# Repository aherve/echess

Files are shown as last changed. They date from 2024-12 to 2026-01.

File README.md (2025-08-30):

# eChess: play online chess, but over the board

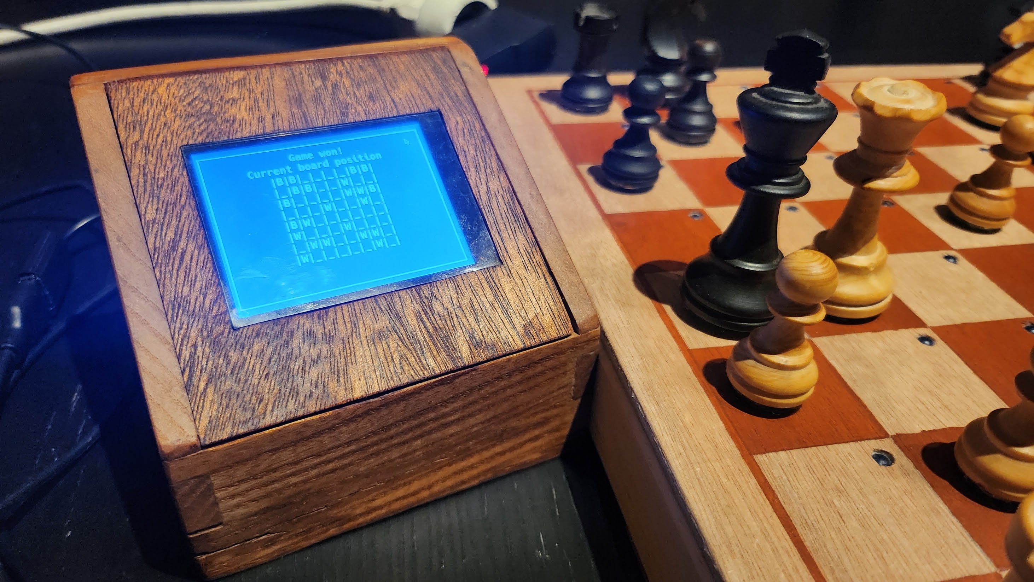
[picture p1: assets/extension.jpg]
extension


https://github.com/user-attachments/assets/bde2e431-92bb-4959-bb7b-e80072c71205

_Demo game against a lichess bot. The phone showcases the game for demo purposes, but isn't actually required to play_

## How it works

- The board is equipped with 64 hall effect sensors, and 64 LEDs.
- The board can communicate via usb to a nodejs program that runs on an embedded raspberry PI with touchscreen
- The program can communicate with both lichess API and the physical board

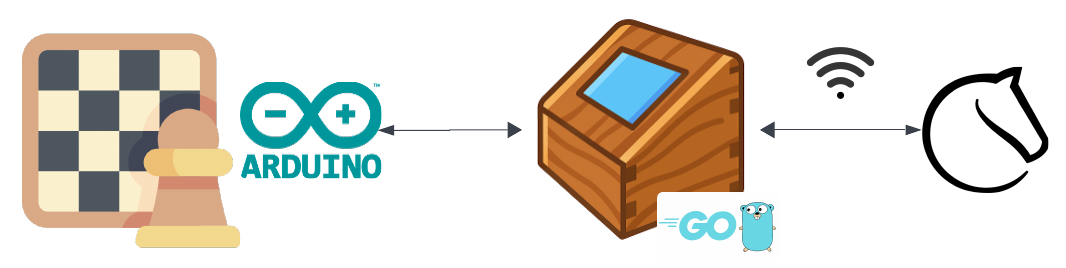
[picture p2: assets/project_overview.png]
overview


### Piece detection

The general principle is to hide magnetic hall effect sensors under the board to detect piece presence. White & black pieces have a hidden magnet in them, in different orientations, respectively

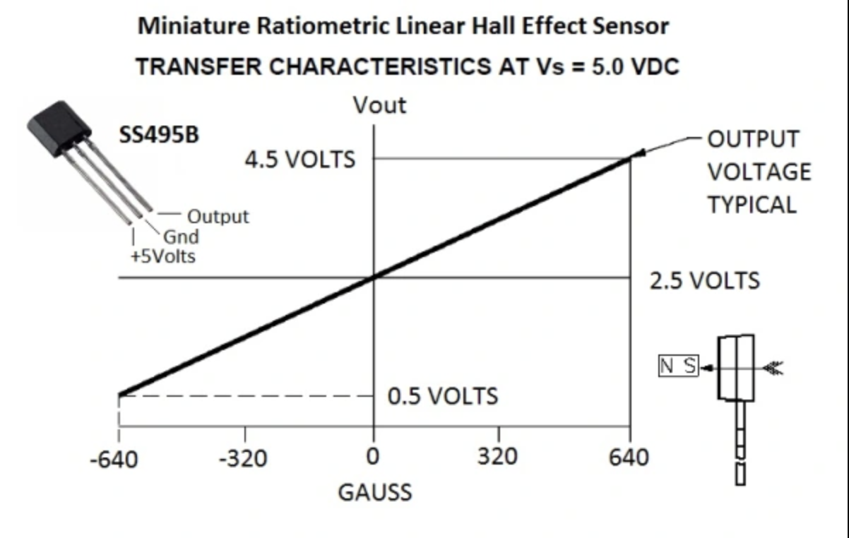
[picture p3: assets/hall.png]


Using linear sensors we are then able to detect between 3 distinct states:

- white piece (low voltage)
- black piece (high voltage)
- no piece (~ half the supply voltage)

In addition to the sensors, a 8x8 LED matrix is used to display the opponent's moves on the board. An arduino microcontroller interfaces with an embedded go program to control the LEDs, read the sensors, and communicate with the lichess API.

## Showing the moves

Each square is equipped with a blue LED that can be lit to signal the opponent's move. It's bright enough that we don't miss a move, and discreet enough that it doesn't distract from the game.

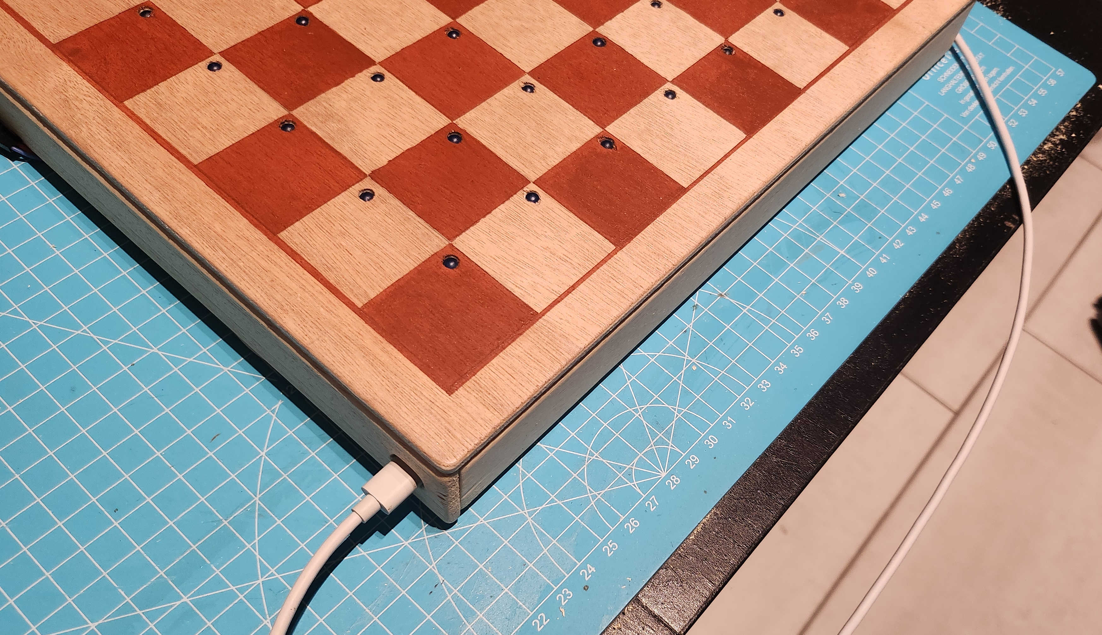
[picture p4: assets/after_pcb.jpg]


## The electronics

For the board to work, is is necessary to:

- read inputs from the program, and light any combination of leds on a 8x8 grid
- read the state of 64 hall effect sensors in near real time, and send the state to the program whenever a change is detected

Since the arduino has a limited number of pins, two 74HC595 shift registers are used to control the LEDs with multiplexing, and an additional 74HC4051 multiplexer is used to control the sensor rows. Each of the sensor outputs are connected to one of the analog inputs of the microcontroller (arduino conveniently has 8 of them).

### The sensor matrix

According to their spreadsheet, the power-on time of the the hall sensors is somewhere from 175μs to 300μs. This is slow enough that we can't use multiplexing to power the sensors. Instead I went for a 8x8 matrix where all of the sensors are always powered. Their input readings are then selected using some BJT transistors whose switch time is in the order of 30ns (so about 8 500 times faster than the sensors power-on time)

<figure>
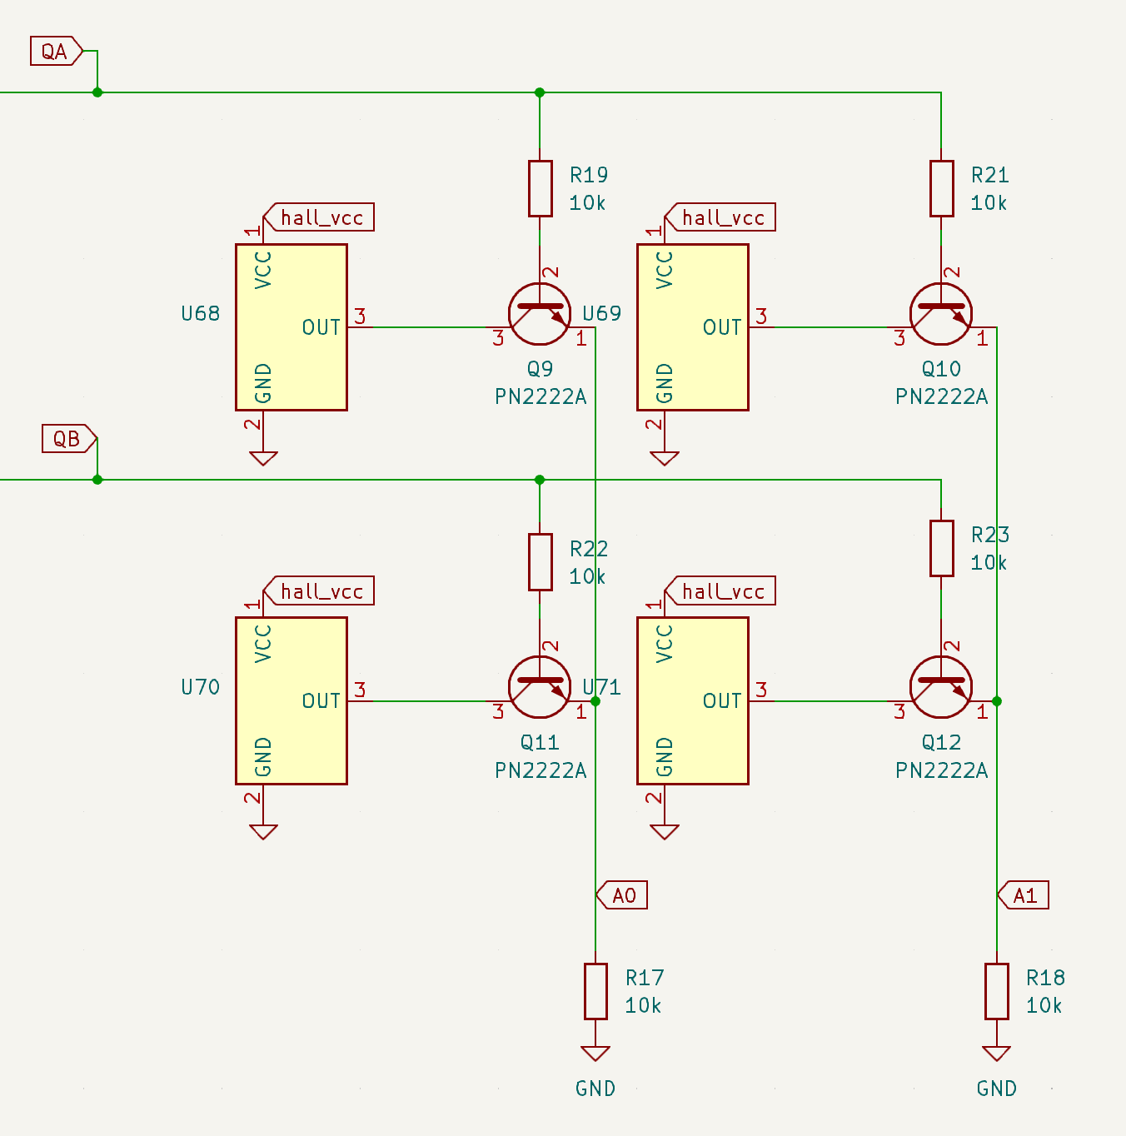
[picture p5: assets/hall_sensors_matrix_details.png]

<figcaption>Details of the sensor matrix, only 4 sensors are shown. Sending <i>QA=1</i>, <i>QB=0</i> and reading <i>A1</i> input would provide a reading of the bottom-right sensor of this diagram</figcaption>
</figure>

### Electronics overview

The three 74HC595 shift registers are chained, and connected to the arduino as follows(only 4 sensors are shown for simplicity):

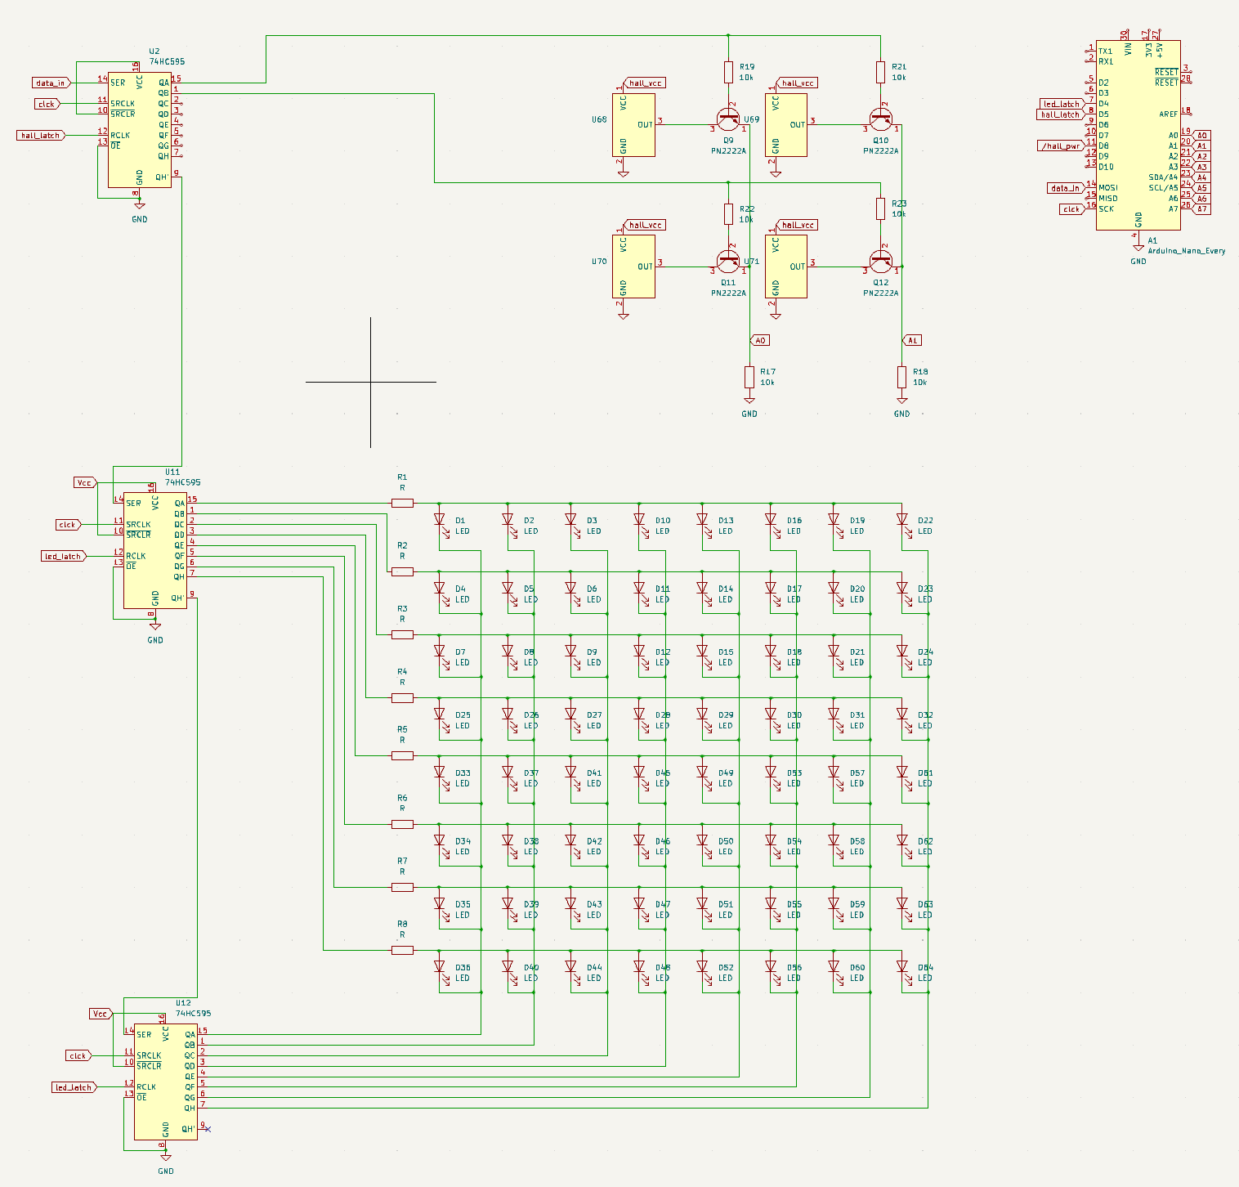
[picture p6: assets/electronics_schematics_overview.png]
overview

_complete overview of the electronics. Full kiCad files can be found in the [kiCad](kiCad) directory_

With this setup, [the microcontroller](arduino/arduino.ino) can use multiplexing to control the LEDs and read the sensors in near real time, while using very few pins from the microcontroller.

### The final build

For the build I soldered 64 leds, hall effect sensors, and transistors directly to a wooden board I build and painted. The shift-register ICs are wired to the microcontroller thanks to a custom PCB [ whose files can be found here ](eBoard_pcb)

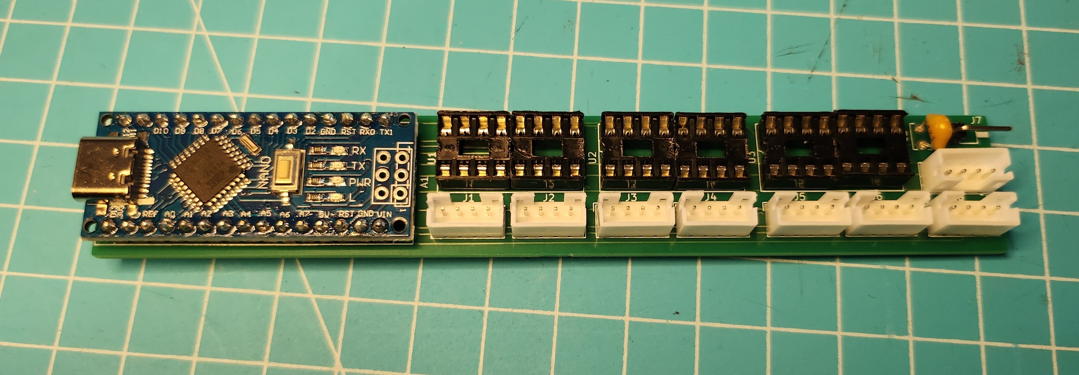
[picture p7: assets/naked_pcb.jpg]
pcb

_soldered pcb with arduino nano, IC sockets and some connectors_

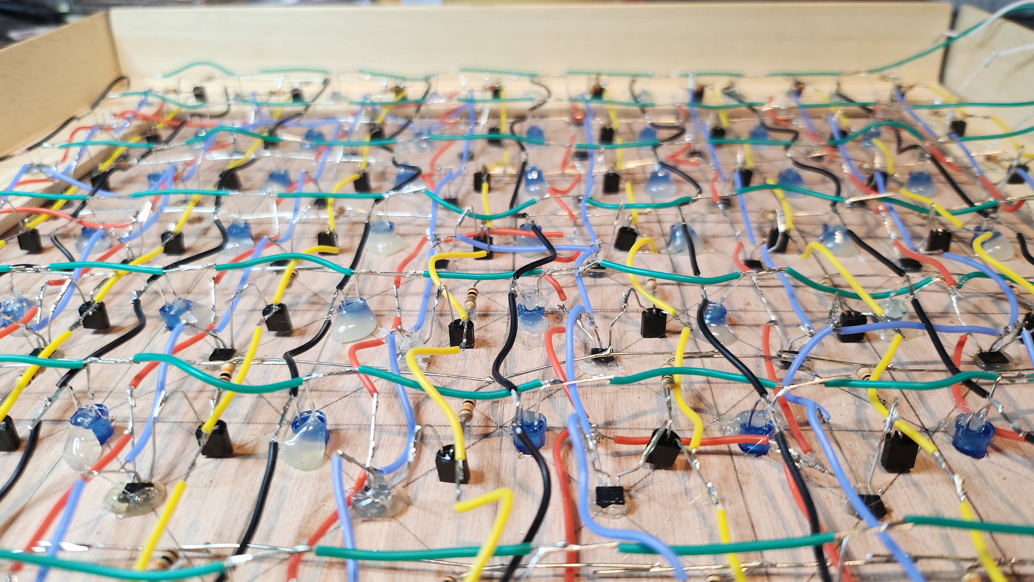
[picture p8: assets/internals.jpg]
internal

_internal view of the board_

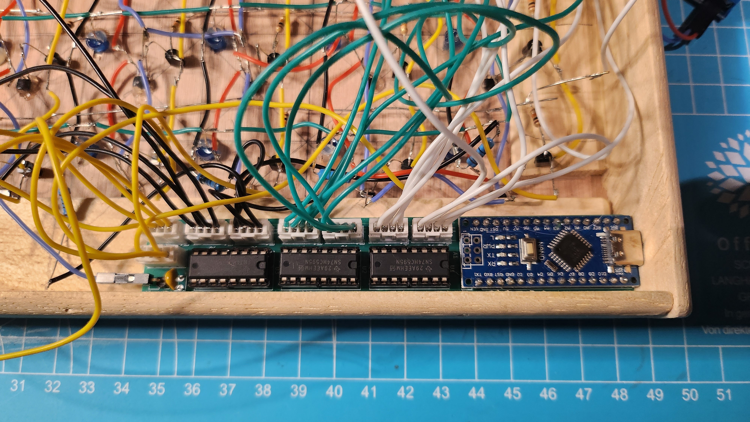
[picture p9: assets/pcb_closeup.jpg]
pcb closeup

_closeup of the pcb after installation_

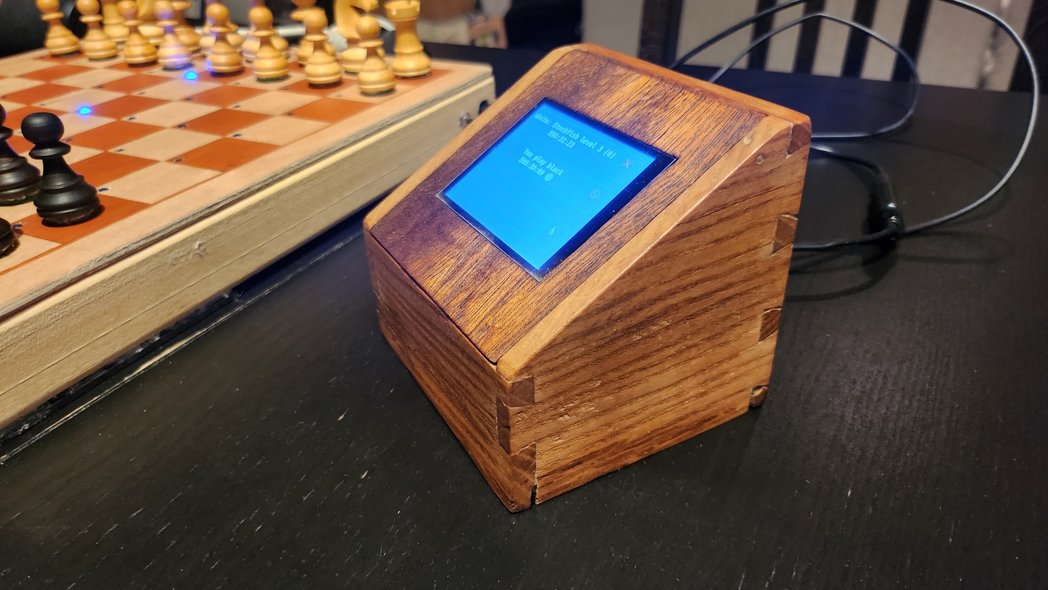
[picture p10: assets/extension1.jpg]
extension1


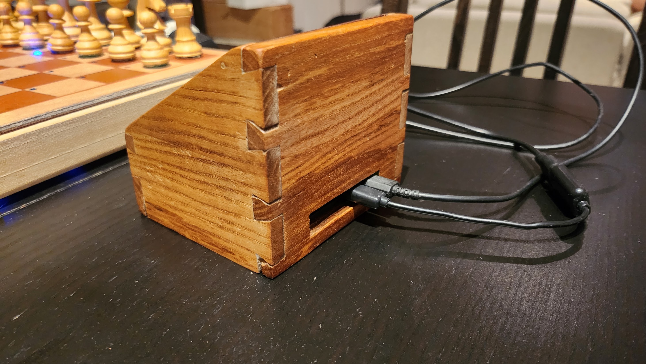
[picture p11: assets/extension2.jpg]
extension2


## Microconctroller setup

Arduino nano is used. It's cheap, small, and conveniently has 8 analog inputs, which is perfect for this use case.

## workflow

The arduino loop does the following:

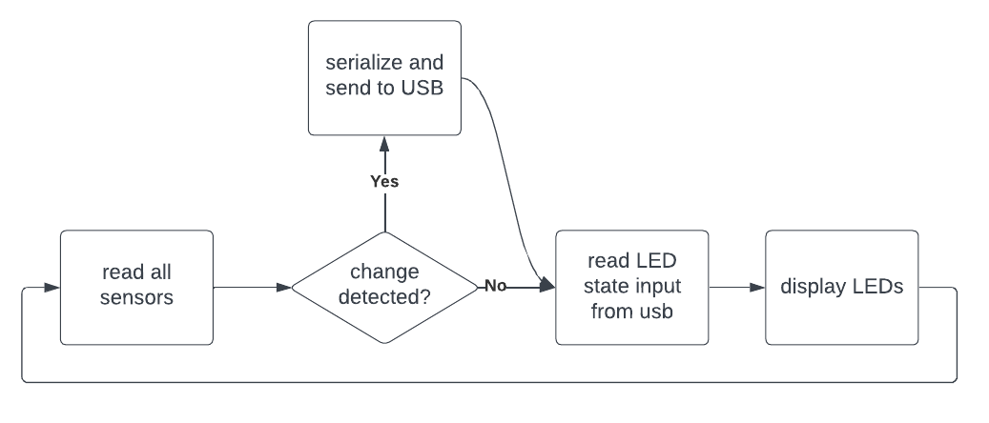
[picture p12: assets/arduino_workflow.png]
workflow


1. **Read all the sensors**

   Using multiplexing, read all states from the 64 hall sensors and build a board state from it. If a state change is detected, then we serialize the board state and send it to the computer.

2. **Read the LED input state**

   Read from usb and set the desired LED state

3. **Display the LEDs**

   For each lit LED from the input state, light the corresponding LED on the board, wait 2ms, and turn it off.

Since we are multiplexing the display, the entire loop needs to be _fast_. Fast enough that you don't see any flickering while we are reading 64 sensors and communicating via USB between each LED blink.

## Serializing the position

A chess board has a very convenient size of 8x8, which allows to represent a row with exactly two bytes:

- first byte signals positions of white pieces on row _a_
- second byte signals positions of black pieces on row _a_
- third byte signals positions of white pieces on row _b_
- ...etc until 16 bytes are sent to fully represent the board
- at the end of a serialization, three 255 bytes are sent to signal the end of the transmission. Since (255, 255, 255) would represent at least one row filled with both white _and_ black pieces, there is no ambiguity in the transmission.

This protocol allows the board to send partial states between led blinks, which removes any flickering from the display. The program can wait for a (255, 255, 255) sequence to know that the board state is fully transmitted, and in case of data corruption, it can ignore a broken state, and start over everytime a (255, 255, 255) sequence is detected.

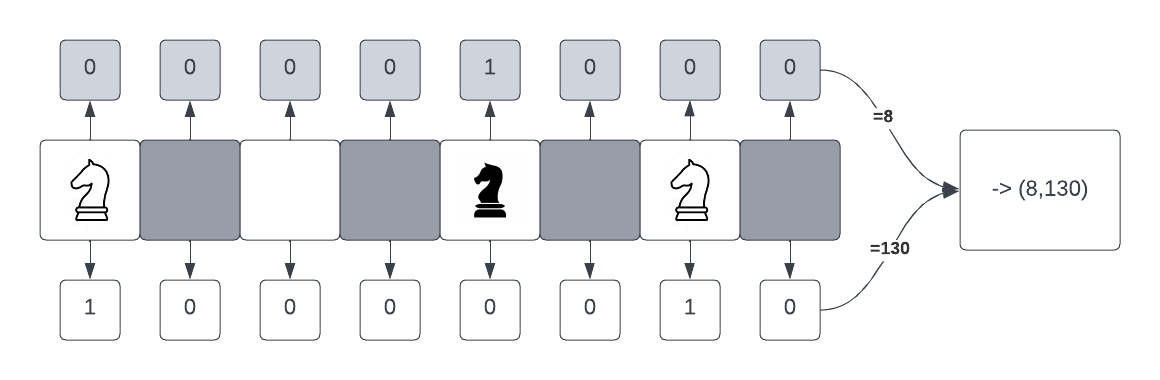
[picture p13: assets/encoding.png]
encoding

_Example of how a row with 2 white pieces and 1 black piece would be encoded_

## The program

Lastly, the main program is written in go, and communicates with the arduino. It will read both the board state and the game moves from lichess to reconcilate the position, and determine when a move should be played (_i.e._ sent to the server), or when some LEDs should be lit. The user interface is provided by a touchscreen, and everything runs on a raspberry zero.

The code can be found in [the app directory](goapp/)

## Conclusion

I've been playing with this board for quite a while now, and it has been a tremendous experience so far. It's definitely not suited for fast time controls, but lichess only provide their real-time API for rapid & classical time-controls anyway (has to do with anti-cheating measures I believe).

Playing lichess games while looking at a physical board is a delight, and has become my main way of playing chess at home.

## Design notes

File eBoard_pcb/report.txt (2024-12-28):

Plotted to '/Users/aherve/Work/electronics/eBoard/eBoard_pcb/eBoard_pcb/gerber/eBoard_pcb-F_Cu.gbr'.
Plotted to '/Users/aherve/Work/electronics/eBoard/eBoard_pcb/eBoard_pcb/gerber/eBoard_pcb-B_Cu.gbr'.
Plotted to '/Users/aherve/Work/electronics/eBoard/eBoard_pcb/eBoard_pcb/gerber/eBoard_pcb-F_Paste.gbr'.
Plotted to '/Users/aherve/Work/electronics/eBoard/eBoard_pcb/eBoard_pcb/gerber/eBoard_pcb-B_Paste.gbr'.
Plotted to '/Users/aherve/Work/electronics/eBoard/eBoard_pcb/eBoard_pcb/gerber/eBoard_pcb-F_Silkscreen.gbr'.
Plotted to '/Users/aherve/Work/electronics/eBoard/eBoard_pcb/eBoard_pcb/gerber/eBoard_pcb-B_Silkscreen.gbr'.
Plotted to '/Users/aherve/Work/electronics/eBoard/eBoard_pcb/eBoard_pcb/gerber/eBoard_pcb-F_Mask.gbr'.
Plotted to '/Users/aherve/Work/electronics/eBoard/eBoard_pcb/eBoard_pcb/gerber/eBoard_pcb-B_Mask.gbr'.
Plotted to '/Users/aherve/Work/electronics/eBoard/eBoard_pcb/eBoard_pcb/gerber/eBoard_pcb-Edge_Cuts.gbr'.
Created Gerber job file '/Users/aherve/Work/electronics/eBoard/eBoard_pcb/eBoard_pcb/gerber/eBoard_pcb-job.gbrjob'.
Info: Done.

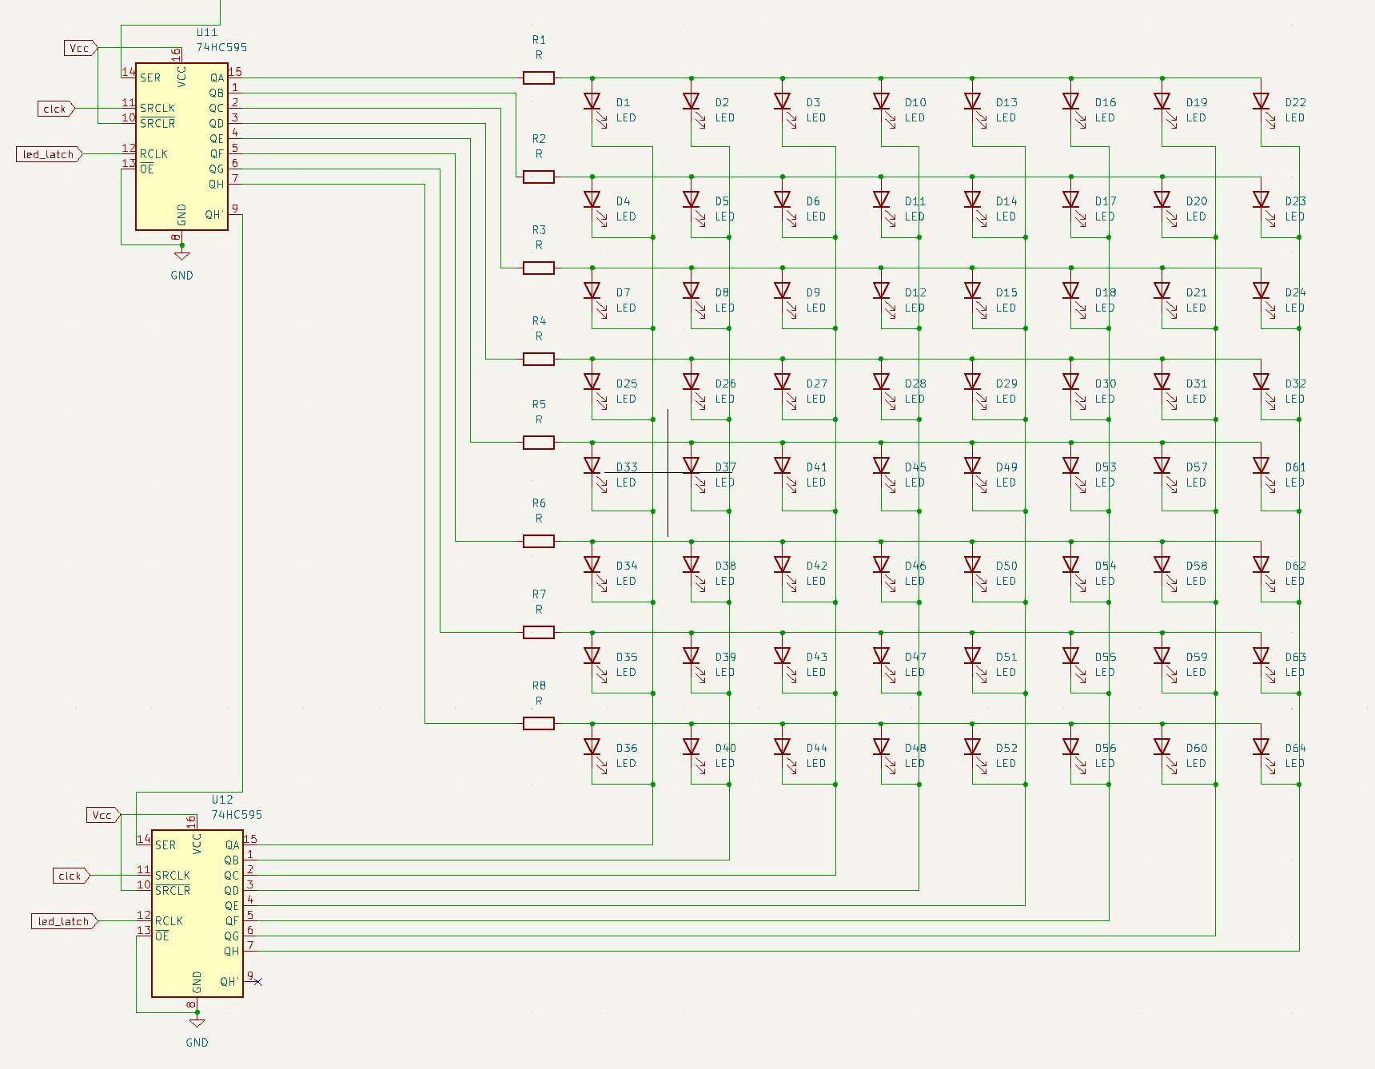
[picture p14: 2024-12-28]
assets/led_matrix_schematics.png

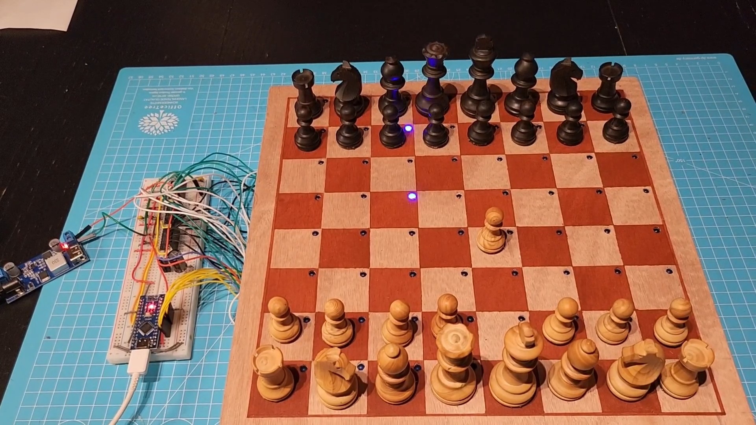
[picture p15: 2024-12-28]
assets/before_pcb.jpg

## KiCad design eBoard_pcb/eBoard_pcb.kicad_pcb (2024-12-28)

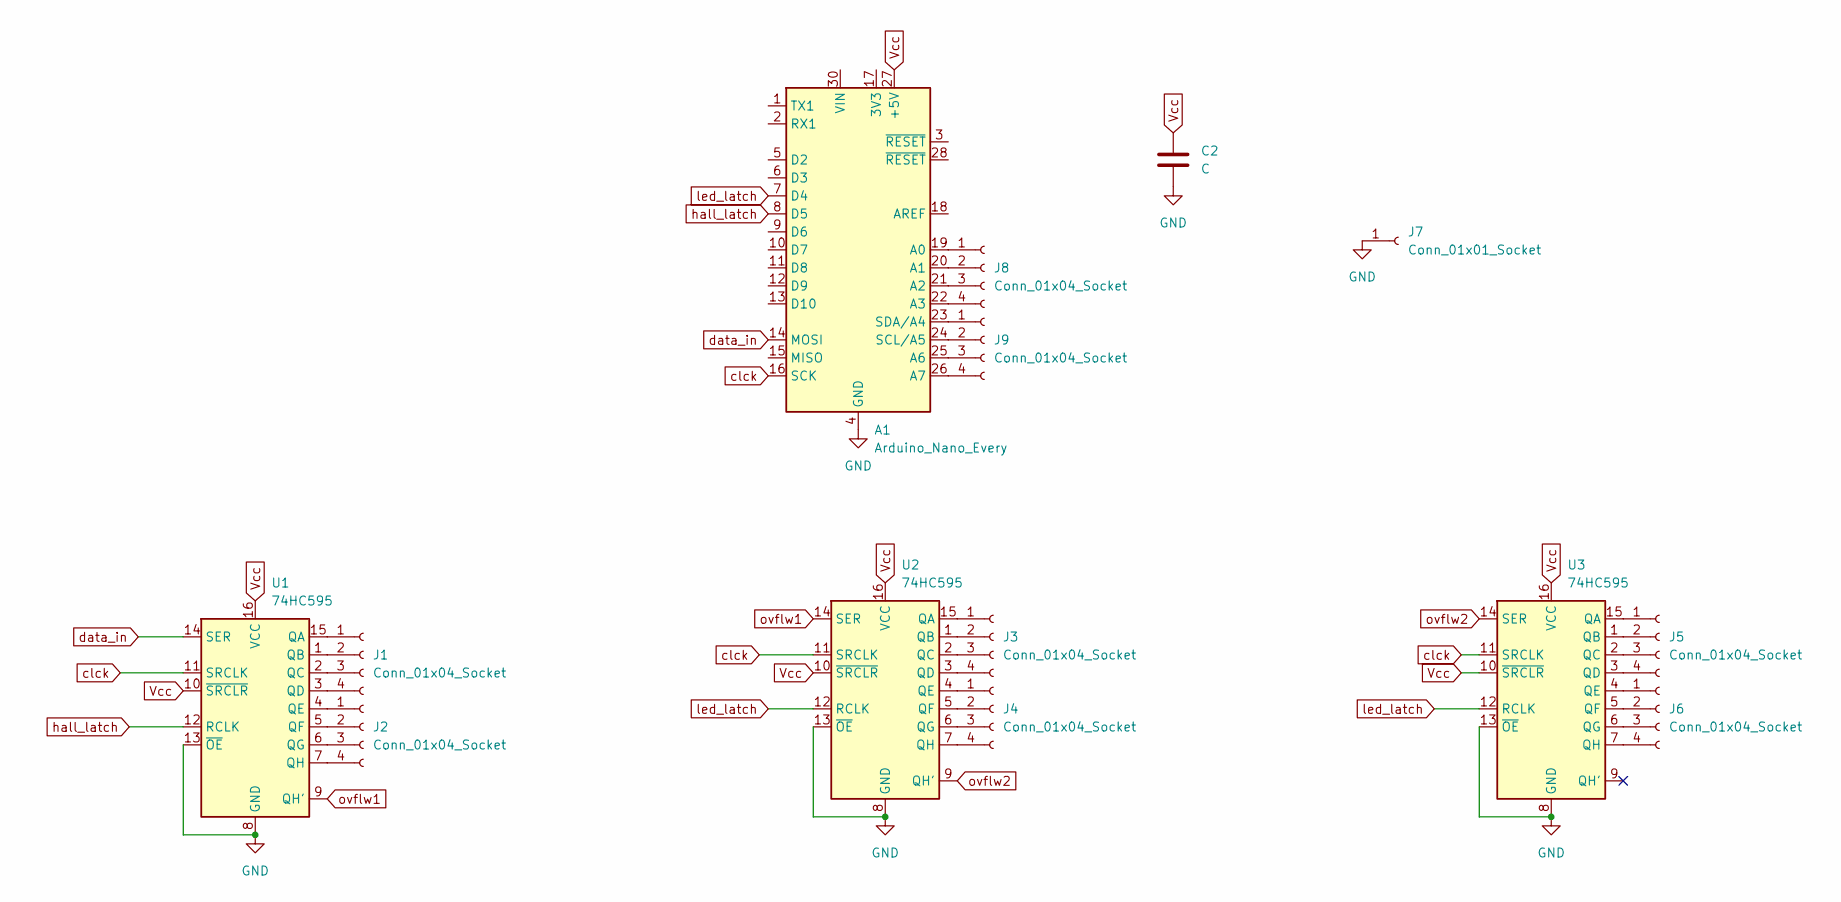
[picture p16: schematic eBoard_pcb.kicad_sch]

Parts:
A1: Arduino_Nano_Every; Arduino_Nano
C2: C; C_Disc_D3.8mm_W2.6mm_P2.50mm
J1, J2, J3, J4, J5, J6, J8, J9: Conn_01x04_Socket; JST_PH_B4B-PH-K_1x04_P2.00mm_Vertical
J7: Conn_01x01_Socket; PinHeader_1x01_P2.54mm_Horizontal
U1, U2, U3: 74HC595; DIP-16_W7.62mm_Socket

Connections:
GND: A1.4 (GND), A1.29 (GND), C2.2, J7.1, U1.8 (GND), U1.13 (~OE), U2.8 (GND), U2.13 (~OE), U3.8 (GND), U3.13 (~OE)
unnamed: A1.19 (A0), J8.1
unnamed: A1.20 (A1), J8.2
unnamed: A1.21 (A2), J8.3
unnamed: A1.22 (A3), J8.4
unnamed: A1.25 (A6), J9.3
unnamed: A1.26 (A7), J9.4
unnamed: A1.24 (SCL/A5), J9.2
unnamed: A1.23 (SDA/A4), J9.1
unnamed: J1.1, U1.15 (QA)
unnamed: J1.2, U1.1 (QB)
unnamed: J1.3, U1.2 (QC)
unnamed: J1.4, U1.3 (QD)
unnamed: J2.1, U1.4 (QE)
unnamed: J2.2, U1.5 (QF)
unnamed: J2.3, U1.6 (QG)
unnamed: J2.4, U1.7 (QH)
unnamed: J3.1, U2.15 (QA)
unnamed: J3.2, U2.1 (QB)
unnamed: J3.3, U2.2 (QC)
unnamed: J3.4, U2.3 (QD)
unnamed: J4.1, U2.4 (QE)
unnamed: J4.2, U2.5 (QF)
unnamed: J4.3, U2.6 (QG)
unnamed: J4.4, U2.7 (QH)
unnamed: J5.1, U3.15 (QA)
unnamed: J5.2, U3.1 (QB)
unnamed: J5.3, U3.2 (QC)
unnamed: J5.4, U3.3 (QD)
unnamed: J6.1, U3.4 (QE)
unnamed: J6.2, U3.5 (QF)
unnamed: J6.3, U3.6 (QG)
unnamed: J6.4, U3.7 (QH)
Vcc: A1.27 (+5V), C2.1, U1.10 (~SRCLR), U1.16 (VCC), U2.10 (~SRCLR), U2.16 (VCC), U3.10 (~SRCLR), U3.16 (VCC)
clck: A1.16 (SCK), U1.11 (SRCLK), U2.11 (SRCLK), U3.11 (SRCLK)
data_in: A1.14 (MOSI), U1.14 (SER)
hall_latch: A1.8 (D5), U1.12 (RCLK)
led_latch: A1.7 (D4), U2.12 (RCLK), U3.12 (RCLK)
ovflw1: U1.9 (QH'), U2.14 (SER)
ovflw2: U2.9 (QH'), U3.14 (SER)

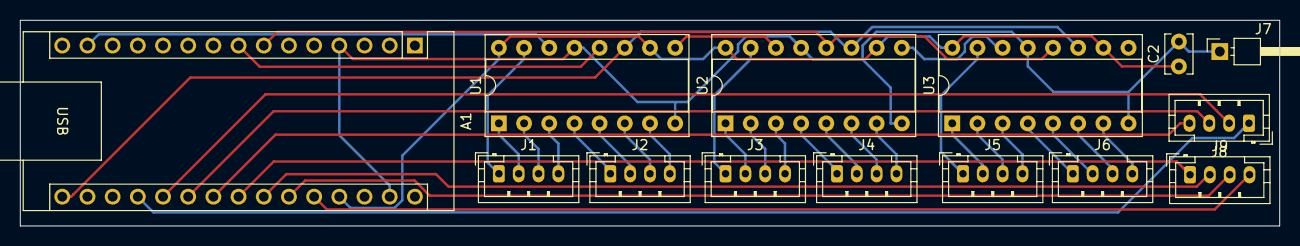
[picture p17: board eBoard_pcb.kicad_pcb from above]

Board: 2 copper layers, 127.0 x 20.7 mm, 14 parts (0 on the bottom side), 40 nets.

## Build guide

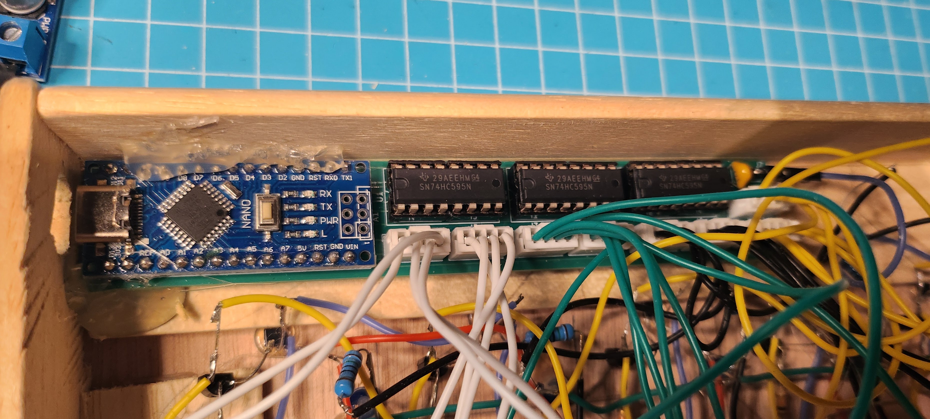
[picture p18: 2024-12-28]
assets/pcb_install.jpg

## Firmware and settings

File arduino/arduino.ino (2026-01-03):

#include <SPI.h>

#define boardSize 8
#define ledLatchPin 4
#define hallLatchPin 5

int boardState[boardSize][boardSize];

int const upTres = 555;
int const downTres = 515;
bool ledState[boardSize][boardSize];
int const readPins[boardSize]{ A0, A1, A2, A3, A4, A5, A6, A7 };
byte ledReadCursor;
bool ledStateBuffer[boardSize][boardSize];

void setup() {
  for (int i = 0; i < boardSize; i++) {
    pinMode(readPins[i], INPUT);
    pinMode(ledLatchPin, OUTPUT);
    pinMode(hallLatchPin, OUTPUT);
    digitalWrite(hallLatchPin, LOW);
    digitalWrite(ledLatchPin, LOW);
  }
  SPI.begin();
  resetLEDs();
  Serial.begin(115200);
  //calibrate();
  readBoard(true);
  sendBoard();
}

void loop() {
  if (readBoard(true)) {
    sendBoard();
  }

  readLedState();
  displayLEDs();
}

// expects an array of bytes representing the state of the LEDs
// Command starts with a 254 byte
// each following byte represents a lit square: 4 least significant bits represent the column, 4 most significant bits represent the row
// Command ends with a 255 byte

// Both 254 and 255 are not valid values for a square, so they can be used as signals
void readLedState() {
  if (Serial.available()) {
    byte incomingByte = Serial.read();
    // Reset buffer on start signal
    if (incomingByte == 254) {
      for (byte i = 0; i < boardSize; i++) {
        for (byte j = 0; j < boardSize; j++) {
          ledStateBuffer[i][j] = false;
        }
      }
      return;  // only do one thing at a time
    }
    // Apply state on end signal
    if (incomingByte == 255) {
      for (byte i = 0; i < boardSize; i++) {
        for (byte j = 0; j < boardSize; j++) {
          ledState[i][j] = ledStateBuffer[i][j];
        }
      }
      return;
    }
    // read the byte and push it to the buffer
    byte iByte = incomingByte >> 4;
    byte jByte = incomingByte & 0b00001111;
    if (iByte < boardSize && jByte < boardSize) {
      ledStateBuffer[iByte][jByte] = true;
    }
  }
}

bool readBoard(bool transform) {
  int changed = false;
  byte iByte = 1;
  for (byte i = 0; i < boardSize; i++) {
    SPI.transfer(iByte);
    digitalWrite(hallLatchPin, HIGH);
    digitalWrite(hallLatchPin, LOW);
    for (byte j = 0; j < boardSize; j++) {
      int read = analogRead(readPins[j]);
      int initRead = read;
      if (transform) {
        if (read < downTres) {
          read = -1;
        } else if (read > upTres) {
          read = 1;
        } else {
          read = 0;
        }
      }
      if (read != boardState[i][j]) {
        changed = true;
        boardState[i][j] = read;
      }
    }
    iByte <<= 1;
  }
  return changed;
}

void displayLEDs() {
  byte iByte = 1;
  for (byte i = 0; i < boardSize; i++) {
    bool isLit = false;
    byte jByte = 0;
    for (byte j = 0; j < boardSize; j++) {
      if (ledState[i][j]) {
        isLit = true;
      } else {
        jByte |= 1 << j;  // 1 is off, 0 is on
      }
    }

    SPI.transfer(jByte);
    SPI.transfer(isLit ? iByte : 0);
    SPI.transfer(0);

    digitalWrite(ledLatchPin, HIGH);
    digitalWrite(ledLatchPin, LOW);

    if (isLit) {
      delay(2);  // gotta wait a bit here for the LEDs to be visible
    }

    iByte <<= 1;
  }
  resetLEDs();
}

void resetLEDs() {
  SPI.transfer(255);
  SPI.transfer(0);
  SPI.transfer(0);

  digitalWrite(ledLatchPin, HIGH);
  digitalWrite(ledLatchPin, LOW);
}

void calibrate() {
  int maxBoard[boardSize][boardSize];
  int minBoard[boardSize][boardSize];

  Serial.println("calibrating...");

  int minOfMin = 1024;
  int maxOfMax = 0;

  for (byte i = 0; i < boardSize; i++) {
    for (byte j = 0; j < boardSize; j++) {
      maxBoard[i][j] = 0;
      minBoard[i][j] = 1024;
    }
  }

  int const nbSamples = 100;
  for (byte sample = 0; sample < nbSamples; sample++) {
    displayLEDs();
    readBoard(false);
    for (byte i = 0; i < boardSize; i++) {
      for (byte j = 0; j < boardSize; j++) {
        if (boardState[i][j] < minBoard[i][j]) {
          minBoard[i][j] = boardState[i][j];
        }
        if (boardState[i][j] > maxBoard[i][j]) {
          maxBoard[i][j] = boardState[i][j];
        }
        if (boardState[i][j] < minOfMin) {
          minOfMin = boardState[i][j];
        }
        if (boardState[i][j] > maxOfMax) {
          maxOfMax = boardState[i][j];
        }
      }
    }
  }

  Serial.println("min board");
  for (byte i = 0; i < boardSize; i++) {
    for (byte j = 0; j < boardSize; j++) {
      Serial.print(minBoard[i][j]);
      Serial.print(", ");
    }
    Serial.println();
  }
  Serial.println("max board");
  for (byte i = 0; i < boardSize; i++) {
    for (byte j = 0; j < boardSize; j++) {
      Serial.print(maxBoard[i][j]);
      Serial.print(", ");
    }
    Serial.println();
  }
  Serial.print("max of max: ");
  Serial.println(maxOfMax);
  Serial.print("min of min: ");
  Serial.println(minOfMin);
}

void sendBoard() {
  for (int i = 0; i < boardSize; i++) {
    byte whiteByte = 0;
    byte blackByte = 0;
    for (int j = 0; j < boardSize; j++) {
      if (boardState[i][j] == 1) {
        whiteByte |= 1 << j;
      } else if (boardState[i][j] == -1) {
        blackByte |= 1 << j;
      }
    }
    Serial.write(whiteByte);
    Serial.write(blackByte);
  }
  // End message signal
  // triple 255 would represent at least one row full of both white and plack pieces, which is impossible. This can thus be interpreted as a recognizable signal for the end of the message
  Serial.write(255);
  Serial.write(255);
  Serial.write(255);
}

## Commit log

2024-12-28 initial commit: move files from private to public repo
    [eBoard.kicad_pcb, eBoard.kicad_sch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]
2024-12-28 rename dir
    [eBoard_pcb-B_Cu.gbr, eBoard_pcb-B_Mask.gbr, eBoard_pcb-B_Paste.gbr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]
2025-01-06 Gui (#2)
    * fiddling around with blessed
    * fun fun fun
    * vitest to debug gui
    * progress
    * raw clock
    * fixup! raw clock
    * wip
    * fix game seeking
    * wip sounds
    * fix sounds
    * remove vitest cache
    * add some buttons
    * fix sounds for real
    * this is playable
    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
2025-01-08 add port filtering for rpi
2025-01-16 raise threshold to avoid flickering when using RPI instead of a macbook
    [arduino.ino]
2025-05-04 stream board events
2025-05-04 board state updates
2025-05-06 padding on seek buttons?
2025-05-07 board, candidate move
2025-06-04 display opponent on top, current player in the middle
2025-10-21 wip: prepare board events for display between games
2025-10-21 fixup! wip: prepare board events for display between games
2026-01-02 update sensivity for raspberry controller
